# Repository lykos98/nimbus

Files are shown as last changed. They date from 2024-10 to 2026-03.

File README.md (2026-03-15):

# Nimbus project
Self build weather sensor network, experimenting on esp32, WiFi, LoRa and much more. 

## Aim of the project 
Hi! I am a PhD student in Data Science and I love to build stuff with microcontrollers and similar things. 
Here I will document my journey in building my weather sensors network, something like [https://sensor.community] but with more flexibility.

The idea is to open source all the kits, parts and codes, and also the instructions to build weather stations. 
Maybe one day to share these kits among people, and to grow a community around citizen science. 

## Project Structure
This repository is organized into several components:

- **[Data API (Backend)](backend/data_api/README.md)**: Flask-based REST API for data ingestion and retrieval.
- **Frontend**: Dashboard and admin interface (documentation pending).
- **PCB**: KiCad designs for the weather station boards.
- **Station Scripts**: Firmware for ESP32 and other microcontrollers.

## TODO
Frontend:
- fix thing date in axis of plots
- improve overall look
- expand admin panel with profiles
    - each one profile is associated to stations, can see secrets can modify description of stations.
    - admin can see anything
    - user can see its station
    - user can set visibility of the station in the pubblic dashboard
    - admin can see all stations with messages and users 
- misc:
    - each station has a message queue that can be seen from the admin, in particular, you should be able to see the message queue for each station in order to get info on a status, like healthy and so on

Backend

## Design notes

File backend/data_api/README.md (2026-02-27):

# Data API

This service provides a RESTful interface for managing station data, users, and station metadata. It interacts with InfluxDB for time-series sensor data and PostgreSQL for metadata (users, station secrets).

## Authentication

Most endpoints require a JWT token in the `Authorization` header:
`Authorization: Bearer <token>`

The `/api/login` endpoint is used to obtain this token.

## Endpoints

### Public / Basic
- `POST /api/login`: Authenticate a user and receive a JWT.
  - Request body: `{"username": "...", "password": "..."}`
  - Response: `{"access_token": "..."}`
- `GET /api/version`: Get the current version of the API.
- `GET /api/profile`: Get the logged-in user's profile (Requires JWT).

### Station Data (Sensor Readings)
- `GET /api/stations`: List available station IDs.
  - Query parameters (optional): `start`, `end` (ISO format).
  - Response: A JSON array of station ID strings (e.g., `["esp_ulp_test", "station_2"]`).
- `GET /api/stations/<station_id>/data`: Get time-series data for a station.
  - Query parameters:
    - `start`: (required) ISO 8601 start time (e.g., `2025-07-15T00:00:00`).
    - `stop`: (required) ISO 8601 end time (e.g., `2025-07-17T00:00:00`).
    - `win`: (optional) Aggregation window:
        - `None`: (default) No aggregation, returns all raw data.
        - `Hour`: Aggregate data by hour (mean value).
        - `Daily`: Aggregate data by day (mean value).
        - `Weekly`: Aggregate data by week (mean value).
  - Response: A JSON-serialized pandas DataFrame (columns format).
- `GET /api/stations/<station_id>/last`: Get the latest reading for a station.
  - Response: A JSON-serialized pandas DataFrame containing the most recent data point.
- `POST /api/stations/<station_id>/data`: Submit new sensor readings (Used by stations).
  - Request body (JSON):
    ```json
    {
      "stationId": "...",
      "secret": "...",
      "airTemperature": 25.5,
      ...
    }
    ```
  - *Note:* The `stationId` in the payload is used for authentication and data storage. The `secret` must match the one stored in the PostgreSQL database for that station. Supported sensor fields are listed below.

### Station Management (Protected)
- `GET /api/user/stations`: List stations owned by or accessible to the current user (Requires JWT).
- `GET /api/admin/stations`: List all stations in the system (Admin only).
- `POST /api/admin/stations`: Create a new station (Admin only).
  - Request body: `{"station_id": "...", "user_id": ...}`
- `DELETE /api/admin/stations/<station_id>`: Delete a station (Admin only).

### User Management (Admin Only)
- `GET /api/admin/users`: List all users.
- `POST /api/admin/users`: Create a new user.
  - Request body: `{"username": "...", "password": "...", "is_admin": ...}`
- `PUT /api/admin/users/<user_id>`: Update a user's details.
- `DELETE /api/admin/users/<user_id>`: Delete a user.

## Data Schema

When posting sensor data via `POST /api/stations/<station_id>/data`, the following fields are supported:

### Atmospheric
- `airTemperature`: Air temperature (°C)
- `airHumidity`: Relative humidity (%)
- `airPressure`: Atmospheric pressure (hPa)
- `airCO2ppm`: Carbon Dioxide concentration (ppm)
- `airNOXppm`: Nitrogen Oxides concentration (ppm)

### Wind and Rain
- `windDirection`: Wind direction (degrees)
- `windSpeed`: Wind speed (m/s)
- `rainmm`: Accumulated rainfall (mm)

### Terrain / Soil
- `terrainTemperature`: Soil/Ground temperature (°C)
- `terrainHumidity`: Soil moisture (%)
- `terrainPH`: Soil pH

### Water
- `waterTemperature`: Water temperature (°C)
- `waterHumidity`: Water humidity (%) - *Context dependent*
- `waterPH`: Water pH

### Power / System
- `batteryV`: Battery voltage (V)
- `batteryA`: Battery current (A)
- `solarV`: Solar panel voltage (V)
- `solarA`: Solar panel current (A)

### Mandatory Fields (for POST)
- `stationId`: The ID of the station.
- `secret`: The unique authentication secret for the station.

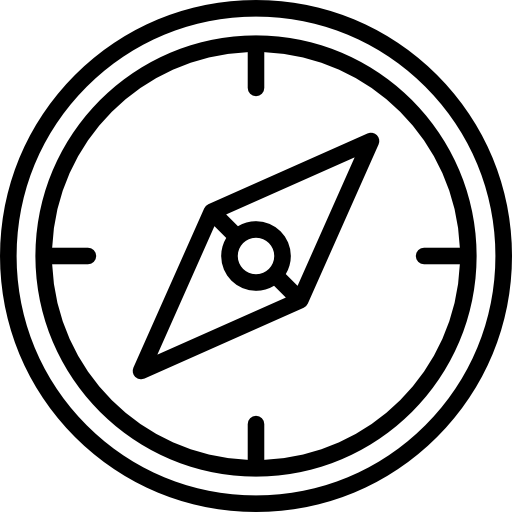
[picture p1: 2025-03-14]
frontend/dash/assets/wind_dir.png

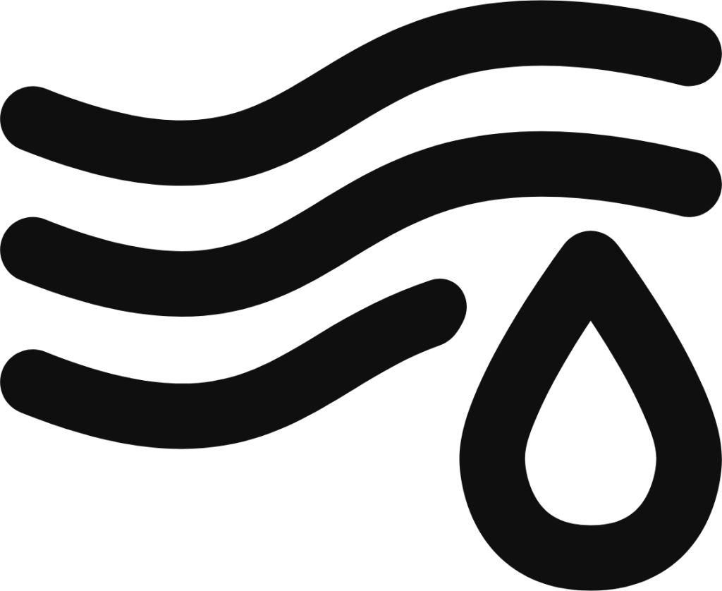
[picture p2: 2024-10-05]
frontend/dash/assets/hum.png

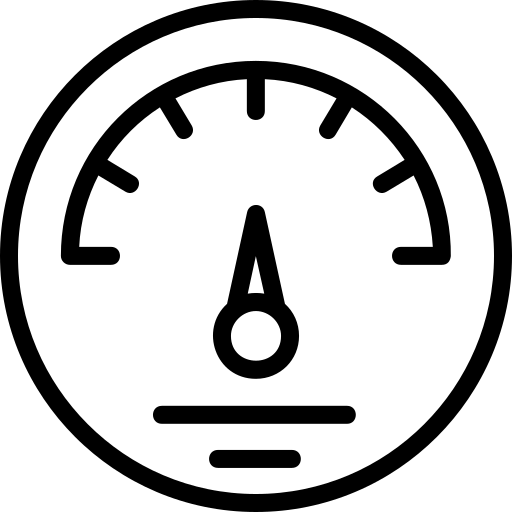
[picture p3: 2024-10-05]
frontend/dash/assets/press.png

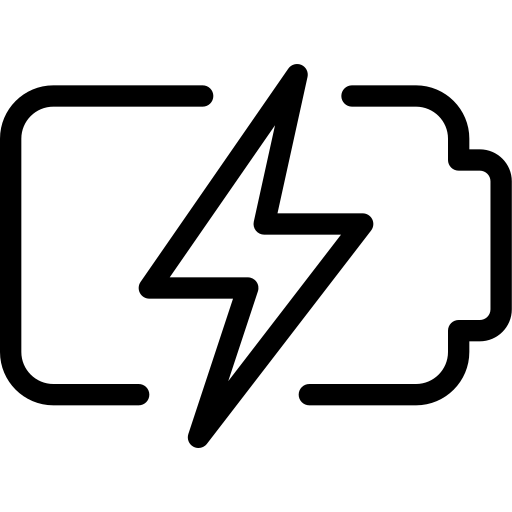
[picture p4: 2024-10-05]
frontend/dash/assets/batt.png

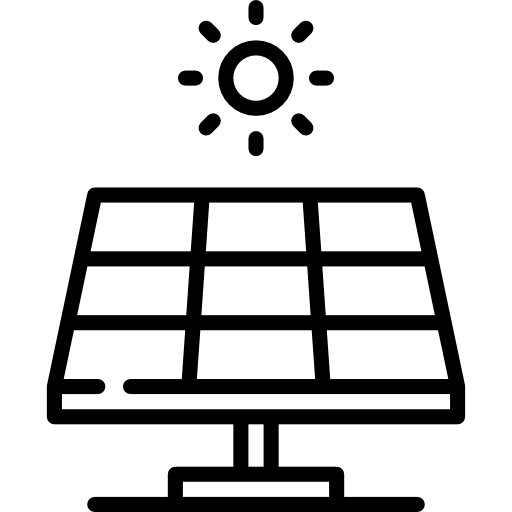
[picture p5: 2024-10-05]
frontend/dash/assets/solr.png

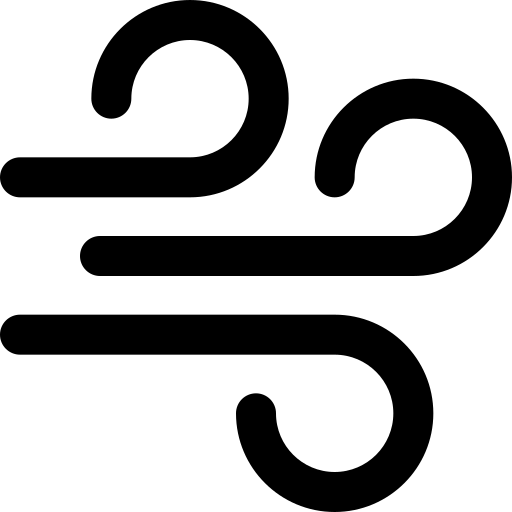
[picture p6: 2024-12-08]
frontend/dash/assets/wind_speed.png

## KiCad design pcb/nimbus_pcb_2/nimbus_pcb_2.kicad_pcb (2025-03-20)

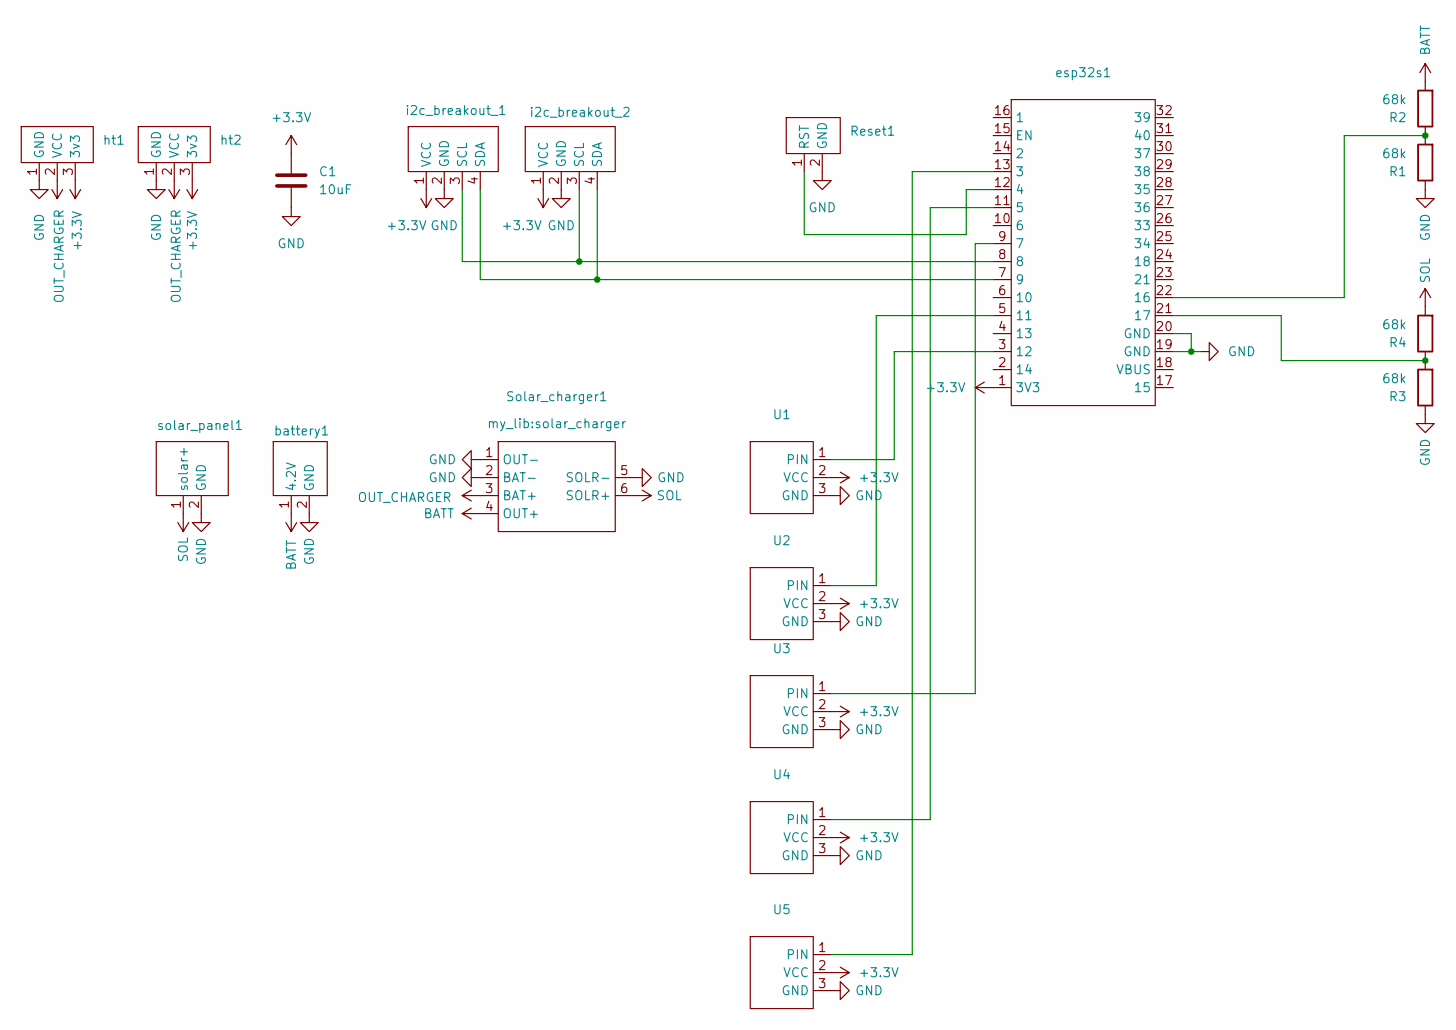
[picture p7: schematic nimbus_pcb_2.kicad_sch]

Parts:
C1: 10uF; C_Disc_D9.0mm_W2.5mm_P5.00mm
R1, R2, R3, R4: 68k; R_Axial_DIN0309_L9.0mm_D3.2mm_P15.24mm_Horizontal
Reset1: reset
Solar_charger1: solar_charger
U1, U2, U3, U4, U5: pin_breakout
battery1: battery
esp32s1: esp32s2
ht1, ht2: ht7833
i2c_breakout_1, i2c_breakout_2: i2c_breakout
solar_panel1: solar

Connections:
+3.3V: C1.1, U1.2 (VCC), U2.2 (VCC), U3.2 (VCC), U4.2 (VCC), U5.2 (VCC), esp32s1.1 (3V3), ht1.3 (3v3), ht2.3 (3v3), i2c_breakout_1.1 (VCC), i2c_breakout_2.1 (VCC); also elsewhere on the board
BATT: R2.2, Solar_charger1.4 (OUT+), battery1.1 (4.2V)
GND: C1.2, R1.1, R3.1, Reset1.2 (GND), Solar_charger1.1 (OUT-), Solar_charger1.2 (BAT-), Solar_charger1.5 (SOLR-), U1.3 (GND), U2.3 (GND), U3.3 (GND), U4.3 (GND), U5.3 (GND), battery1.2 (GND), esp32s1.19 (GND), esp32s1.20 (GND), ht1.1 (GND), ht2.1 (GND), i2c_breakout_1.2 (GND), i2c_breakout_2.2 (GND), solar_panel1.2 (GND); also elsewhere on the board
unnamed 3: Reset1.1 (RST), esp32s1.12 (4); also elsewhere on the board
unnamed 4: U1.1 (PIN), esp32s1.3 (12); also elsewhere on the board
unnamed 5: U2.1 (PIN), esp32s1.5 (11); also elsewhere on the board
unnamed 6: U3.1 (PIN), esp32s1.9 (7); also elsewhere on the board
unnamed 7: U4.1 (PIN), esp32s1.11 (5); also elsewhere on the board
unnamed 8: U5.1 (PIN), esp32s1.13 (3); also elsewhere on the board
unnamed 9: esp32s1.7 (9), i2c_breakout_1.4 (SDA), i2c_breakout_2.4 (SDA); also elsewhere on the board
unnamed 10: R1.2, R2.1, esp32s1.22 (16); also elsewhere on the board
unnamed 11: R3.2, R4.1, esp32s1.21 (17); also elsewhere on the board
unnamed 12: esp32s1.8, i2c_breakout_1.3 (SCL), i2c_breakout_2.3 (SCL); also elsewhere on the board
OUT_CHARGER: Solar_charger1.3 (BAT+), ht1.2 (VCC), ht2.2 (VCC)
SOL: R4.2, Solar_charger1.6 (SOLR+), solar_panel1.1 (solar+)

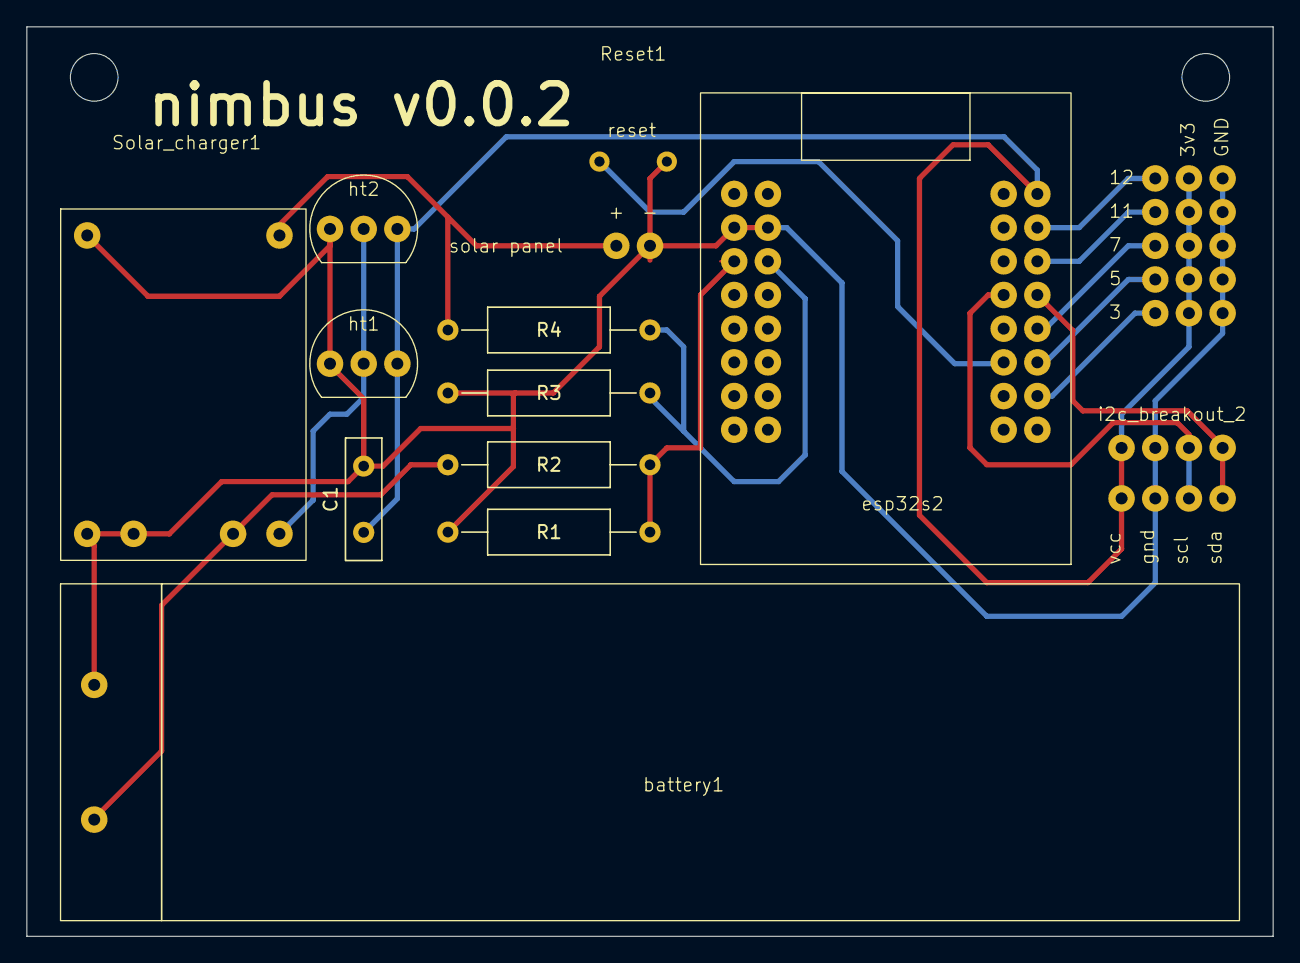
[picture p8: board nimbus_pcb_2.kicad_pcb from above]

Board: 2 copper layers, 94.0 x 68.6 mm, 19 parts (0 on the bottom side), 15 nets.

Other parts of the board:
esp32s2: esp32s2

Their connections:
+3.3V: esp32s2.1 (3V3); also elsewhere on the board
GND: esp32s2.19 (GND), esp32s2.20 (GND); also elsewhere on the board
unnamed 3: esp32s2.12 (4); also elsewhere on the board
unnamed 4: esp32s2.3 (12); also elsewhere on the board
unnamed 5: esp32s2.5 (11); also elsewhere on the board
unnamed 6: esp32s2.9 (7); also elsewhere on the board
unnamed 7: esp32s2.11 (5); also elsewhere on the board
unnamed 8: esp32s2.13 (3); also elsewhere on the board
unnamed 9: esp32s2.7 (9); also elsewhere on the board
unnamed 10: esp32s2.22 (16); also elsewhere on the board
unnamed 11: esp32s2.21 (17); also elsewhere on the board
unnamed 12: esp32s2.8; also elsewhere on the board

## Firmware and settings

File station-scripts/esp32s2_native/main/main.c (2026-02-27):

#include <stdio.h>
#include <freertos/FreeRTOS.h>
#include <freertos/task.h>
#include <esp_system.h>
#include <esp_sleep.h>
#include <stdlib.h>
#include <string.h>

#include "freertos/idf_additions.h"
#include "freertos/projdefs.h"
#include "driver/gpio.h"
#include "hal/gpio_types.h"
#include "nvs_flash.h"
#include "nvs.h"
#include "hal/brownout_hal.h"

#include "soc/rtc_cntl_reg.h"
#include "soc/sens_reg.h"
#include "soc/rtc_periph.h"
#include "driver/gpio.h"
#include "driver/rtc_io.h"


#include "https_client.h"
#include "ulp_riscv.h"
#include "wifi.h"
#include "sensors.h"

#include "ulp_main.h"

#define ULP_TAG "ulp"
#define API_URL "https://hehe.lykos.cc/api/stations"

#if !defined(STATION_NAME)
    #error "Please define STATION_NAME in config.h"
#endif

#define CYCLE_SLEEP_TIME (10 * 60 * 1000 * 1000)
// #define CYCLE_SLEEP_TIME (15 * 1000 * 1000)
#define RESET_SLEEP_TIME (2 * 60 * 1000 * 1000)
#define PI 3.14


#ifndef APP_CPU_NUM
#define APP_CPU_NUM PRO_CPU_NUM
#endif

#define MSG_SIZE 300

char msg[MSG_SIZE];

extern const uint8_t ulp_main_bin_start[] asm("_binary_ulp_main_bin_start");
extern const uint8_t ulp_main_bin_end[]   asm("_binary_ulp_main_bin_end");

// #include "driver/uart.h"
//
// #define UART_TX_PIN         (GPIO_NUM_11) // S2 TX pin connected to C3 RX pin
// #define UART_RX_PIN         (UART_PIN_NO_CHANGE) // Not needed for sending
// #define UART_PORT_NUM       (UART_NUM_1) 
// #define UART_BAUD_RATE      (115200) // MUST MATCH C3's BAUD RATE
// #define BUF_SIZE            (1024)
//
// static void uart_init() {
//     // 1. Configure the UART parameters
//     uart_config_t uart_config = {
//         .baud_rate = UART_BAUD_RATE,
//         .data_bits = UART_DATA_8_BITS,
//         .parity    = UART_PARITY_DISABLE,
//         .stop_bits = UART_STOP_BITS_1,
//         .flow_ctrl = UART_HW_FLOWCTRL_DISABLE,
//         .source_clk = UART_SCLK_DEFAULT,
//     };
//
//     // 2. Install the UART driver (no event queue needed for simple transmission)
//     ESP_ERROR_CHECK(uart_driver_install(UART_PORT_NUM, BUF_SIZE * 2, 0, 0, NULL, 0));
//
//     // 3. Set the UART pins using the GPIO Matrix
//     // This is where GPIO 10 is mapped to the UART1 TX signal.
//     ESP_ERROR_CHECK(uart_set_pin(UART_PORT_NUM, UART_TX_PIN, UART_RX_PIN, UART_PIN_NO_CHANGE, UART_PIN_NO_CHANGE));
//
//     // 4. Set the configuration parameters
//     ESP_ERROR_CHECK(uart_param_config(UART_PORT_NUM, &uart_config));
//
//     ESP_LOGI("uart_tag", "UART1 initialized on TX: GPIO%d at %d Baud.", UART_TX_PIN, UART_BAUD_RATE);
// }

char* reset_reason_to_string(esp_reset_reason_t reason) {
    switch (reason) {
        case ESP_RST_UNKNOWN:     return "UNKNOWN";           // 0
        case ESP_RST_POWERON:     return "POWERON";           // 1
        case ESP_RST_EXT:         return "EXTERNAL_PIN";      // 2
        case ESP_RST_SW:          return "SOFTWARE_RESTART";  // 3 (esp_restart)
        case ESP_RST_PANIC:       return "PANIC_EXCEPTION";   // 4 (Software reset due to exception)
        case ESP_RST_INT_WDT:     return "INT_WATCHDOG";      // 5 (Interrupt Watchdog Reset)
        case ESP_RST_TASK_WDT:    return "TASK_WATCHDOG";     // 6 (Task Watchdog Reset)
        case ESP_RST_WDT:         return "OTHER_WATCHDOG";    // 7
        case ESP_RST_DEEPSLEEP:   return "DEEP_SLEEP_WAKEUP"; // 8
        case ESP_RST_BROWNOUT:    return "BROWNOUT";          // 9 (Voltage low)
        case ESP_RST_SDIO:        return "SDIO";              // 10
        // NOTE: Additional reasons (e.g., USB, JTAG) may exist depending on the ESP32 variant (S2, C3, S3, C6, etc.)
        default:                  return "UNRECOGNIZED";
    }
}

void decouple_adc_pins() {
    // Disable the ADC GPIO modes to prevent internal leakage
    gpio_set_direction(SOLAR_PIN, GPIO_MODE_DISABLE);
    gpio_set_direction(BATTERY_PIN, GPIO_MODE_DISABLE);
}

void disable_i2c_gpios() {
    gpio_reset_pin(BMP280_SDA); // BMP280_SDA is GPIO_NUM_9
    gpio_reset_pin(BMP280_SCL); // BMP280_SCL is GPIO_NUM_8
    // Set them to input and disable internal pull-ups/downs
    gpio_set_direction(BMP280_SDA, GPIO_MODE_DISABLE);
    gpio_set_direction(BMP280_SCL, GPIO_MODE_DISABLE);
    // If possible, power down the I2C devices or remove VCC to the bus.
}

void app_task(void *pvParameters) {

    char api_endpoint[100];
    snprintf(api_endpoint, 100, "%s/%s/data", API_URL, STATION_NAME);

    vTaskDelay(pdMS_TO_TICKS(1000));
    ESP_ERROR_CHECK(i2cdev_init());

    esp_reset_reason_t reason = esp_reset_reason();
    char* reason_str = reset_reason_to_string(reason);
    int anemometer_rotations = 0;
    int ulp_is_active_copy = 0;

    /**
     * Connectivity start wifi and mqtt
     */

    esp_err_t err = ESP_OK;
    err = wifi_connect();

    if(err !=  ESP_OK)
    {
        esp_sleep_enable_timer_wakeup(RESET_SLEEP_TIME);
        esp_deep_sleep_start();
    }


    /*
     * Initialize sensors
     */

    err = bmp_init_dev();
    if(err !=  ESP_OK)
    {
        char tmp_msg[256];
        int len = snprintf(tmp_msg, sizeof(tmp_msg), "{\"stationId\":\"%s\", \"message\" : \" Cannot initialize bmp\", \"secret\": \"%s\"}", STATION_NAME, SECRET);
        https_post_json(api_endpoint, tmp_msg, len);
        esp_sleep_enable_timer_wakeup(RESET_SLEEP_TIME);
        esp_deep_sleep_start();
    }

    err = aht_init_dev();
    if(err !=  ESP_OK)
    {
        char tmp_msg[256];
        int len = snprintf(tmp_msg, sizeof(tmp_msg), "{\"stationId\":\"%s\", \"message\" : \" Cannot initialize aht\", \"secret\": \"%s\"}", STATION_NAME, SECRET);
        https_post_json(api_endpoint, tmp_msg, len);
        esp_sleep_enable_timer_wakeup(RESET_SLEEP_TIME);
        esp_deep_sleep_start();
    }

    err = ams_init_dev();
    if(err !=  ESP_OK)
    {
        char tmp_msg[256];
        int len = snprintf(tmp_msg, sizeof(tmp_msg), "{\"stationId\":\"%s\", \"message\" : \" Cannot initialize ams\", \"secret\": \"%s\"}", STATION_NAME, SECRET);
        https_post_json(api_endpoint, tmp_msg, len);
        esp_sleep_enable_timer_wakeup(RESET_SLEEP_TIME);
        esp_deep_sleep_start();
    }

    err = adc_init_units();
    if(err !=  ESP_OK)
    {
        char tmp_msg[256];
        int len = snprintf(tmp_msg, sizeof(tmp_msg), "{\"stationId\":\"%s\", \"message\" : \"Cannot initialize adc units\", \"secret\": \"%s\"}", STATION_NAME, SECRET);
        https_post_json(api_endpoint, tmp_msg, len);
        esp_sleep_enable_timer_wakeup(RESET_SLEEP_TIME);
        esp_deep_sleep_start();
    }

    adc_pin_config_t solar_pin_config = {0};
    err = adc_init_pins(&solar_pin_config, SOLAR_PIN);
    if(err !=  ESP_OK)
    {
        char tmp_msg[256];
        int len = snprintf(tmp_msg, sizeof(tmp_msg), "{\"stationId\":\"%s\", \"message\" : \"Cannot initialize SOLAR PIN reading\", \"secret\": \"%s\"}", STATION_NAME, SECRET);
        https_post_json(api_endpoint, tmp_msg, len);
        esp_sleep_enable_timer_wakeup(RESET_SLEEP_TIME);
        esp_deep_sleep_start();
    }

    adc_pin_config_t battery_pin_config = {0};
    err = adc_init_pins(&battery_pin_config, BATTERY_PIN);
    if(err !=  ESP_OK)
    {
        char tmp_msg[256];
        int len = snprintf(tmp_msg, sizeof(tmp_msg), "{\"stationId\":\"%s\", \"message\" : \"Cannot initialize BATTERY PIN reading\", \"secret\": \"%s\"}", STATION_NAME, SECRET);
        https_post_json(api_endpoint, tmp_msg, len);
        esp_sleep_enable_timer_wakeup(RESET_SLEEP_TIME);
        esp_deep_sleep_start();
    }


    rtc_gpio_init(ANEMOMETER_PIN);
    rtc_gpio_set_direction(ANEMOMETER_PIN, RTC_GPIO_MODE_INPUT_ONLY);
    rtc_gpio_pulldown_dis(ANEMOMETER_PIN);
    rtc_gpio_pullup_en(ANEMOMETER_PIN);
    rtc_gpio_hold_en(ANEMOMETER_PIN);

    /* start the ulp & or check the things */
    if(reason == ESP_RST_DEEPSLEEP)
    {

        if(ulp_is_active != 117)
        {
            anemometer_rotations = 0;
            ulp_is_active_copy   = 0;
            ESP_LOGI(ULP_TAG, "Resetting ulp");
        }
        else 
        {
            anemometer_rotations = ulp_rotations;
            ulp_is_active_copy   = ulp_is_active;
        }

        /* reset after deep sleep */
        //ulp_riscv_reset();
        ulp_is_active = 0;
        ulp_rotations = 0;
        
        /* wait for the reset */
        vTaskDelay(pdMS_TO_TICKS(50));

        /* check if the upl is running */
        if(ulp_is_active_copy != 117)
        {
            err = ulp_riscv_load_binary(ulp_main_bin_start, ulp_main_bin_end - ulp_main_bin_start);
            if(err !=  ESP_OK)
            {
                char tmp_msg[256];
                int len = snprintf(tmp_msg, sizeof(tmp_msg), "{\"stationId\":\"%s\", \"message\" : \"Cannot initialize ulp: load failed \", \"secret\": \"%s\"}", STATION_NAME, SECRET);
                https_post_json(api_endpoint, tmp_msg, len);
                esp_sleep_enable_timer_wakeup(RESET_SLEEP_TIME);
                esp_deep_sleep_start();
            }
            ulp_set_wakeup_period(0, 40000);
            err = ulp_riscv_run();
            if(err !=  ESP_OK)
            {
                char tmp_msg[256];
                int len = snprintf(tmp_msg, sizeof(tmp_msg), "{\"stationId\":\"%s\", \"message\" : \"Cannot initialize ulp: run \", \"secret\": \"%s\"}", STATION_NAME, SECRET);
                https_post_json(api_endpoint, tmp_msg, len);
                esp_sleep_enable_timer_wakeup(RESET_SLEEP_TIME);
                esp_deep_sleep_start();
            }
        }


        ESP_LOGI(ULP_TAG, "Found %u rotations", anemometer_rotations);
    }
    else
    {
        ulp_is_active = 0;
        ulp_rotations = 0;
        ulp_gpio_level_previous = 0;
        err = ulp_riscv_load_binary(ulp_main_bin_start, ulp_main_bin_end - ulp_main_bin_start);
        if(err !=  ESP_OK)
        {
            char tmp_msg[256];
            int len = snprintf(tmp_msg, sizeof(tmp_msg), "{\"stationId\":\"%s\", \"message\" : \"Cannot initialize ulp: load failed \", \"secret\": \"%s\"}", STATION_NAME, SECRET);
            https_post_json(api_endpoint, tmp_msg, len);
            esp_sleep_enable_timer_wakeup(RESET_SLEEP_TIME);
            esp_deep_sleep_start();
        }
        ulp_set_wakeup_period(0, 40000);
        err = ulp_riscv_run();
        if(err !=  ESP_OK)
        {
            char tmp_msg[256];
            int len = snprintf(tmp_msg, sizeof(tmp_msg), "{\"stationId\":\"%s\", \"message\" : \"Cannot initialize ulp: run \", \"secret\": \"%s\"}", STATION_NAME, SECRET);
            https_post_json(api_endpoint, tmp_msg, len);
            esp_sleep_enable_timer_wakeup(RESET_SLEEP_TIME);
            esp_deep_sleep_start();
        }

        ESP_LOGI(ULP_TAG, "First boot starting ulp");

    }
    


    

    /*
     * Read from sensors
     */

    // bmp hum is only a dummy
    float bmp_press, bmp_hum, bmp_temp;
    float aht_hum, aht_temp;
    uint16_t angle;
    int solar_v, solar_raw, battery_v, battery_raw;

    err = bmp_read(&bmp_temp, &bmp_press, &bmp_hum);
    if(err !=  ESP_OK)
    {
        char tmp_msg[256];
        int len = snprintf(tmp_msg, sizeof(tmp_msg), "{\"stationId\":\"%s\", \"message\" : \"Error while reading from bmp\", \"secret\": \"%s\"}", STATION_NAME, SECRET);
        https_post_json(api_endpoint, tmp_msg, len);
        esp_sleep_enable_timer_wakeup(RESET_SLEEP_TIME);
        esp_deep_sleep_start();
    }
    else 
    {
        ESP_LOGI(BMP_TAG, "Read %.2f C %.2f Pa from bmp", bmp_temp, bmp_press);    
    }

    err = aht_read(&aht_temp, &aht_hum);
    if(err !=  ESP_OK)
    {
        char tmp_msg[256];
        int len = snprintf(tmp_msg, sizeof(tmp_msg), "{\"stationId\":\"%s\", \"message\" : \"Error while reading from aht\", \"secret\": \"%s\"}", STATION_NAME, SECRET);
        https_post_json(api_endpoint, tmp_msg, len);
        esp_sleep_enable_timer_wakeup(RESET_SLEEP_TIME);
        esp_deep_sleep_start();
    }
    else 
    {
        ESP_LOGI(AHT_TAG, "Read %.2f C %.2f from aht", aht_temp, aht_hum);    
    }


    err = ams_read(&angle);
    if(err !=  ESP_OK)
    {
        char tmp_msg[256];
        int len = snprintf(tmp_msg, sizeof(tmp_msg), "{\"stationId\":\"%s\", \"message\" : \"Error while reading from ams\", \"secret\": \"%s\"}", STATION_NAME, SECRET);
        https_post_json(api_endpoint, tmp_msg, len);
        esp_sleep_enable_timer_wakeup(RESET_SLEEP_TIME);
        esp_deep_sleep_start();
    }
    else 
    {
        ESP_LOGI(AMS_TAG, "Read %.u from ams", angle);    
    }

    err = adc_read_pin(solar_pin_config, &solar_raw, &solar_v);
    if(err !=  ESP_OK)
    {
        char tmp_msg[256];
        int len = snprintf(tmp_msg, sizeof(tmp_msg), "{\"stationId\":\"%s\", \"message\" : \"Error while reading from solar adc val\", \"secret\": \"%s\"}", STATION_NAME, SECRET);
        https_post_json(api_endpoint, tmp_msg, len);
        esp_sleep_enable_timer_wakeup(RESET_SLEEP_TIME);
        esp_deep_sleep_start();
    }
    else 
    {
        ESP_LOGI(AMS_TAG, "Read %d (%d mV) from solar", solar_raw, solar_v);    
    }

    err = adc_read_pin(battery_pin_config, &battery_raw, &battery_v);
    if(err !=  ESP_OK)
    {
        char tmp_msg[256];
        int len = snprintf(tmp_msg, sizeof(tmp_msg), "{\"stationId\":\"%s\", \"message\" : \"Error while reading from battery adc val\", \"secret\": \"%s\"}", STATION_NAME, SECRET);
        https_post_json(api_endpoint, tmp_msg, len);
        esp_sleep_enable_timer_wakeup(RESET_SLEEP_TIME);
        esp_deep_sleep_start();
    }
    else 
    {
        ESP_LOGI(AMS_TAG, "Read %d (%d mV) from battery", battery_raw, battery_v);    
    }

    int angle_int = (360 * angle/4096 + ANGLE_OFFSET) % 360;


    float wind_speed = (float)anemometer_rotations * 2 * ANEMOMETER_LEN_M / (CYCLE_SLEEP_TIME / 1e6);
    int size = snprintf(msg, MSG_SIZE, 
        "{\"stationId\":\"%s\","
         "\"airHumidity\":%.2f," 
         "\"airTemperature\":%.2f," 
         "\"airPressure\":%.2f," 
         " \"solarV\":%.2f," 
         " \"batteryV\":%.2f," 
         " \"windSpeed\":%.2f,"
         " \"windDirection\":%d,"
         " \"ulpActive\":%d,"
         " \"resetReason\":\"%s\","
         " \"anemometerRotations\":%d,"
         " \"secret\":\"%s\"}",
         STATION_NAME, aht_hum, aht_temp, bmp_press, 
         2.*(float)solar_v/1000. + 0.2, 2.*(float)battery_v/1000. + 0.2,
         wind_speed, angle_int, ulp_is_active_copy, 
         reason_str, anemometer_rotations, SECRET);

    // char cc[] = "ciao";
    // mqtt_send(cc, sizeof(cc));
    https_post_json(api_endpoint, msg, size);
    ESP_LOGI("MSG", "(%u len) %s", size, msg);
    ESP_LOGI("HEAP", "Free heap: %d, Min: %d", esp_get_free_heap_size(), esp_get_minimum_free_heap_size());

    gpio_set_level(GPIO_NUM_3,0);
    gpio_set_level(GPIO_NUM_5,0);

    disable_i2c_gpios();
    esp_wifi_stop();

    esp_sleep_enable_timer_wakeup(CYCLE_SLEEP_TIME);
    esp_deep_sleep_start();

    vTaskDelete(NULL);
}

void app_main()
{
   // uart_init();

    /* disable brownout sensor */    
    brownout_hal_config_t cfg = {
        .threshold = 7,			// 3.00v
        .enabled = false,
        .reset_enabled = false,		// if you want to use ".det" as a software signal, you must disable all brown-out shutdowns
        .flash_power_down = false,
        .rf_power_down = false,
    };
    brownout_hal_config(&cfg);
    gpio_set_direction(GPIO_NUM_3, GPIO_MODE_OUTPUT);
    gpio_set_direction(GPIO_NUM_5, GPIO_MODE_OUTPUT);
    
    gpio_set_level(GPIO_NUM_3,1);
    gpio_set_level(GPIO_NUM_5,1);


    esp_err_t ret = nvs_flash_init();
    if (ret == ESP_ERR_NVS_NO_FREE_PAGES || ret == ESP_ERR_NVS_NEW_VERSION_FOUND) {
        ESP_ERROR_CHECK(nvs_flash_erase());
        ret = nvs_flash_init();
    }

    ESP_ERROR_CHECK(ret);

    xTaskCreate(app_task, "app_task", 4096, NULL, 5, NULL);
}

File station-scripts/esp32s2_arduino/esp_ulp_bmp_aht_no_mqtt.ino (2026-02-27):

#include "soc/soc.h"
#include "soc/rtc_cntl_reg.h"
#include "esp32s2/ulp.h"
#include "driver/rtc_io.h"
#include "hal/gpio_types.h"
#include "soc/rtc_io_reg.h"
#include <rom/rtc.h>
#include "hal/brownout_hal.h"		// for adjusting brownout level

#define SOLAR_PIN GPIO_NUM_17
#define BATTERY_PIN GPIO_NUM_16
#define AS5600_POWER_PIN GPIO_NUM_3
#define ANEMOMETER_PIN   GPIO_NUM_7

#define RESET_PIN GPIO_NUM_4

#define SCL_PIN GPIO_NUM_8
#define SDA_PIN GPIO_NUM_9

#define ANEMOMETER_LEN 0.13
#define SLEEP_TIME (60 * 10)
//#define SLEEP_TIME (30)
#define M_PI 3.14159265358979323846


#include "esp32_utilities.h"
#include "ulp_program.h"


#include <Adafruit_AHTX0.h>
#include <Adafruit_BMP280.h>

Adafruit_AHTX0  aht;
Adafruit_BMP280 bmp(&Wire); // I2C

int count = 0;
uint32_t anemometer_rotations = 0;
uint32_t ulp_active = 0;

float read_angle_as5600(TwoWire& w)
{
  int calibration;
  preferences.begin("wifi-config", true);
  calibration = preferences.getInt("vane_cal");
  preferences.end();

  LOGF("Calibration %d", calibration);
 

  w.beginTransmission(AS5600_ADDRESS);
  w.write(0x0C); // Angle register address
  w.endTransmission();

  w.requestFrom(AS5600_ADDRESS, 2); // Request 2 bytes of data
  delay(100);
  // Read angle data
  float angleDegrees = 0.;
  if (w.available() >= 2) {
    byte highByte = w.read();
    byte lowByte = w.read();
    int angle = (highByte << 8) | lowByte;
    //+ 4096 + 1024 to shift to the correct value nswe
    angle = (angle - calibration + 4096 + 1024) % 4096;
    angleDegrees = (float)angle / 4096.0 * 360.0;

  }
  return angleDegrees;
}

float angle_to_direction(float angle, char* direction)
{
  angle = angle + 12.25;
  int dir_code = (int)(angle/22.5);
  return angle;
}

void get_reset_reason(esp_reset_reason_t reason, char* str_reason)
{
  switch (reason)
  {
    case ESP_RST_UNKNOWN:
      strcpy(str_reason,"ESP_RST_UNKNOWN");
      break;
    case ESP_RST_POWERON:
      strcpy(str_reason,"ESP_RST_POWERON");
      break;
    case ESP_RST_EXT:
      strcpy(str_reason,"ESP_RST_EXT");
      break;
    case ESP_RST_SW:
      strcpy(str_reason,"ESP_RST_SW");
      break;
    case ESP_RST_PANIC:
      strcpy(str_reason,"ESP_RST_PANIC");
      break;
    case ESP_RST_INT_WDT:
      strcpy(str_reason,"ESP_RST_INT_WDT");
      break;
    case ESP_RST_TASK_WDT:
      strcpy(str_reason,"ESP_RST_TASK_WDT");
      break;
    case ESP_RST_WDT:
      strcpy(str_reason,"ESP_RST_WDT");
      break;
    case ESP_RST_DEEPSLEEP:
      strcpy(str_reason,"ESP_RST_DEEPSLEEP");
      break;
    case ESP_RST_BROWNOUT:
      strcpy(str_reason,"ESP_RST_BROWNOUT");
      break;
    case ESP_RST_SDIO:
      strcpy(str_reason,"ESP_RST_SDIO");
      break;
    case ESP_RST_USB:
      strcpy(str_reason,"ESP_RST_USB");
      break;
    case ESP_RST_JTAG:
      LOGF(str_reason,"ESP_RST_JTAG");
      break;
    case ESP_RST_EFUSE:
      LOGF(str_reason,"ESP_RST_EFUSE");
      break;
    case ESP_RST_PWR_GLITCH:
      LOGF(str_reason,"ESP_RST_PWR_GLITCH");
      break;
    case ESP_RST_CPU_LOCKUP:
      LOGF(str_reason,"ESP_RST_CPU_LOCKUP");
      break;
    default:
      break;    
  }
}

void bmp_sleep() {
  bmp.setSampling(Adafruit_BMP280::MODE_SLEEP);
}

void setup() {
  char message[LOG_BUFFER_SIZE];

  /* disable brownout sensor */    
  brownout_hal_config_t cfg = {
    .threshold = 7,			// 3.00v
    .enabled = false,
    .reset_enabled = false,		// if you want to use ".det" as a software signal, you must disable all brown-out shutdowns
    .flash_power_down = false,
    .rf_power_down = false,
  };
  brownout_hal_config(&cfg);

  /* 
   * start up as5600 sensor
   * powered down for energy consumption 
   */

  pinMode(GPIO_NUM_3, OUTPUT);
  digitalWrite(GPIO_NUM_3, HIGH);
  
  pinMode(GPIO_NUM_5, OUTPUT);
  digitalWrite(GPIO_NUM_5, HIGH);


  /* 
   * Init serial and wait for initialization 
   * TODO: fine tune it to better have the
   * minimal number of seconds to sleep
   */
  Serial.begin(115200);
  delay(1000);
  

  LOGF("\n\n---------------------------------------------------");
  LOGF("RESET REASON");
  esp_reset_reason_t  reason = esp_reset_reason();
  char str_reason[20];
  get_reset_reason(reason, str_reason);
  LOGF("%s", str_reason);
  
  Wire.begin(SDA_PIN, SCL_PIN);

  /* 
   * check if initial config
   * SSID, password and possible configs need to be reset
   */
  check_reset_condition();
  connect_to_wifi();

  /* set the direction of the pin of the anemometer */

  esp_err_t gpio_config_err = -1;
  int tries = 0;
  while(gpio_config_err != ESP_OK || tries <= MAX_N_TRIES)
  {
    gpio_config_err = ESP_OK;
    gpio_config_err = gpio_config_err || rtc_gpio_deinit(ANEMOMETER_PIN);
    gpio_config_err = gpio_config_err || rtc_gpio_init(ANEMOMETER_PIN);
    gpio_config_err = gpio_config_err || rtc_gpio_set_direction(ANEMOMETER_PIN, RTC_GPIO_MODE_INPUT_ONLY);
    gpio_config_err = gpio_config_err || rtc_gpio_pulldown_dis(ANEMOMETER_PIN);     // enable the pull-up resistor
    gpio_config_err = gpio_config_err || rtc_gpio_pullup_en(ANEMOMETER_PIN);  // disable the pull-down resistor
    gpio_config_err = gpio_config_err || rtc_gpio_hold_en(ANEMOMETER_PIN);       // required to maintain pull-up
    tries++;
  }

  esp_err_t err;
  /* retrieve from memory the number of anemometer rotations */  
  if (reason == ESP_RST_DEEPSLEEP) {
    // If so, print the counter
    LOGF("Number of turns %u", (uint32_t)(RTC_SLOW_MEM[COUNTER] & 0xFFFF) );
    //Serial.print("Old state ");
    //LOGF((uint32_t)(RTC_SLOW_MEM[OLD_STATE] & 0xFFFF) );
    anemometer_rotations = RTC_SLOW_MEM[COUNTER] & 0xFFFF;
    ulp_active           = RTC_SLOW_MEM[ULP_ACTIVE] & 0xFFFF;
    LOGF("ulp active %u\n", ulp_active);
    
    RTC_SLOW_MEM[COUNTER] = 0;   
    RTC_SLOW_MEM[OLD_STATE] = 0; 
    RTC_SLOW_MEM[ULP_ACTIVE] = 0; 
  } else {
    // First-time setup
    RTC_SLOW_MEM[COUNTER] = 0;
    RTC_SLOW_MEM[OLD_STATE] = 0;
    RTC_SLOW_MEM[ULP_ACTIVE] = 0; 

    LOGF("First boot, setting up ULP wakeup counter.");
  }

  err = startULP();
  char ulp_err[10];

  if(err == ESP_OK || ulp_active == 117){
    strcpy(ulp_err,"OK");
  }
  else {
    strcpy(ulp_err,"FAIL");
  }

  
  /* retrieve certificate and connect to the mqtt broker */
  check_certificate();
  String ca_cert = load_certificate();
  wifiClient.setCACert(ca_cert.c_str());
 
  connect_to_broker(mqttClient, broker, port);

  /*
   * Initialize aht 
   */
  tries = 0;
  while (aht.begin(&Wire) != true && tries < MAX_N_TRIES)
  {
    LOGF("AHT20 not connected or fail to load calibration coefficient"); 
    delay(5000);
    ++tries;
  }
 
  if(tries == MAX_N_TRIES)
  {
    snprintf( message, LOG_BUFFER_SIZE,
              "{\"stationId\":\"%s\",\"error\":\"Cannot initialize AHT\"}", station_id.c_str());
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

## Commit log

2025-03-17 eliminated prints
2025-03-20 refactored code and added pcbs
2025-05-31 added esp32_c3 station script
2026-01-29 saved symbols
    [nimbus_pcb_2.kicad_sch]
2026-04-08 added create station button
